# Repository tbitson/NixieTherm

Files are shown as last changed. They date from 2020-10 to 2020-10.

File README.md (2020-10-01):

# NixieTherm
 An analog nixie Tube Thermometer based on a IN-13 Nixie bar graph tube. Uses a Teensy 3.2 microcontroller to display temperature readings from a DS-18B20 1-wire temperature sensor.
 
 This is a n in-work project!
 
 Major hardware:
 IN-13 Nixie bar-graph tube (ebay.com)
 High voltage power supply module, such as a NCH8200HV 5V to 170V convertor (ebay.com)
 Teensy 3.2 microcontroller (PRJC.com)
 PC Board - eagle files included
 3D printed display mount and spacers - STL files included
 Laser cut acrylic display - laserdraw files included
 ULN2003 IC, RGB Leds, resistors, transistors...

 3D Printed objects available on TinkerCad.com
 https://www.tinkercad.com/things/9rIuJBIbugg-nixietherm/edit

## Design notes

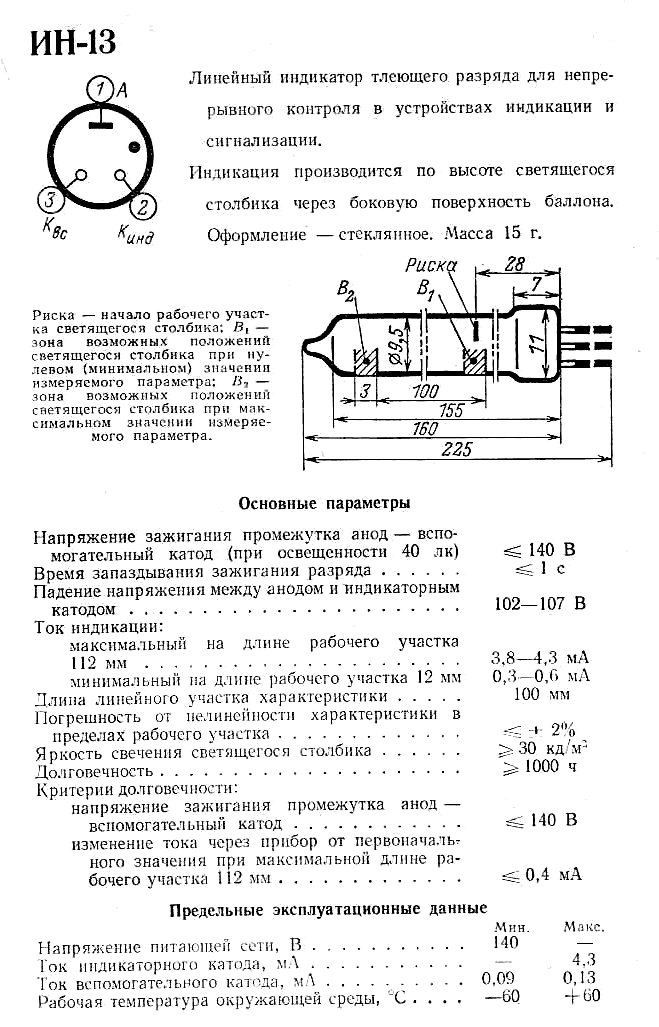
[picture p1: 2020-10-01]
Hardware/in-13-datasheet.gif

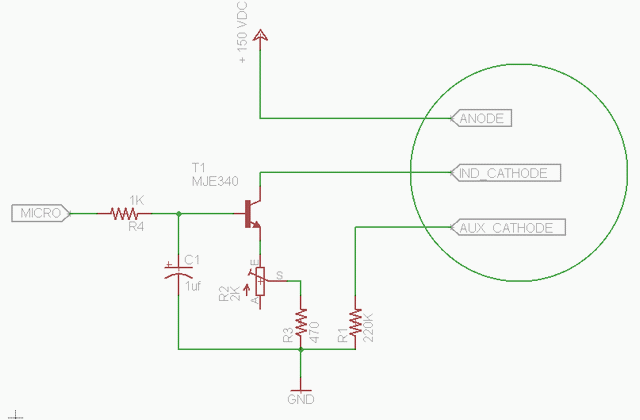
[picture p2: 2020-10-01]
Hardware/in13 schematic.gif

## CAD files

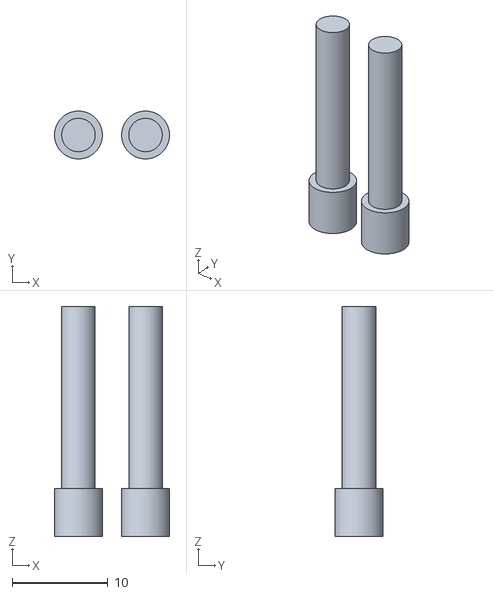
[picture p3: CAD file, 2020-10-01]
Hardware/3D Print Objects/NixieTherm Button Extenders.stl
12.0 x 5.00 x 24.0

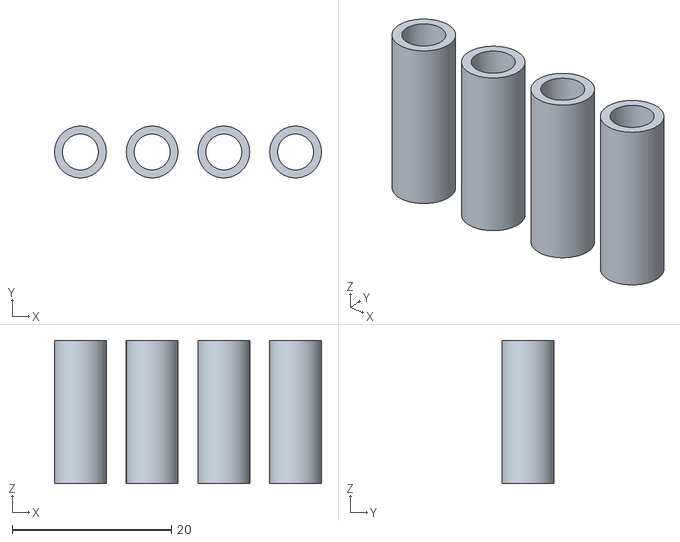
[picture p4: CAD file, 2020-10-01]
Hardware/3D Print Objects/NixieTherm Spacers.stl
33.5 x 6.50 x 18.0

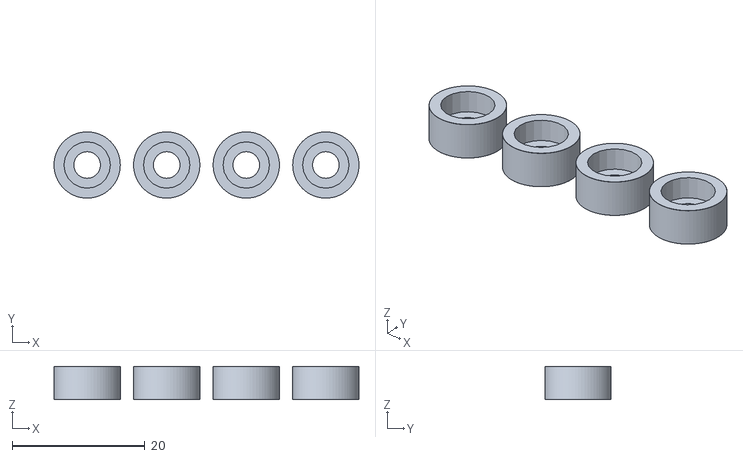
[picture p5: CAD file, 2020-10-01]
Hardware/3D Print Objects/NixieTherm Feet.stl
46.0 x 10.0 x 5.00

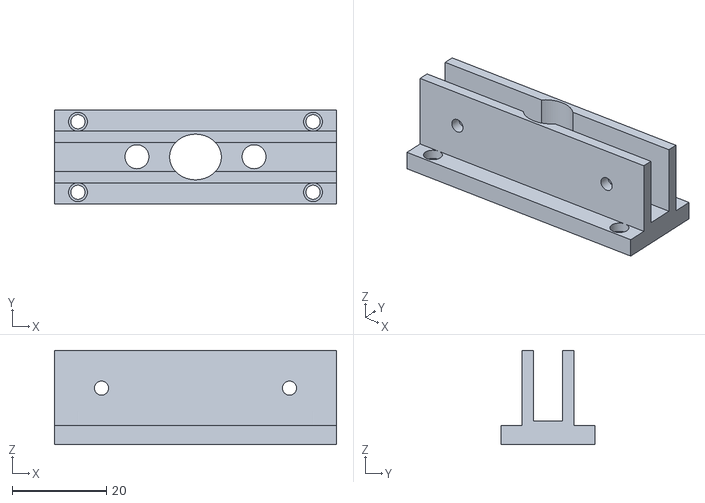
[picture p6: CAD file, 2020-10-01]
Hardware/3D Print Objects/NixieTherm Mount.stl
60.0 x 20.0 x 20.0

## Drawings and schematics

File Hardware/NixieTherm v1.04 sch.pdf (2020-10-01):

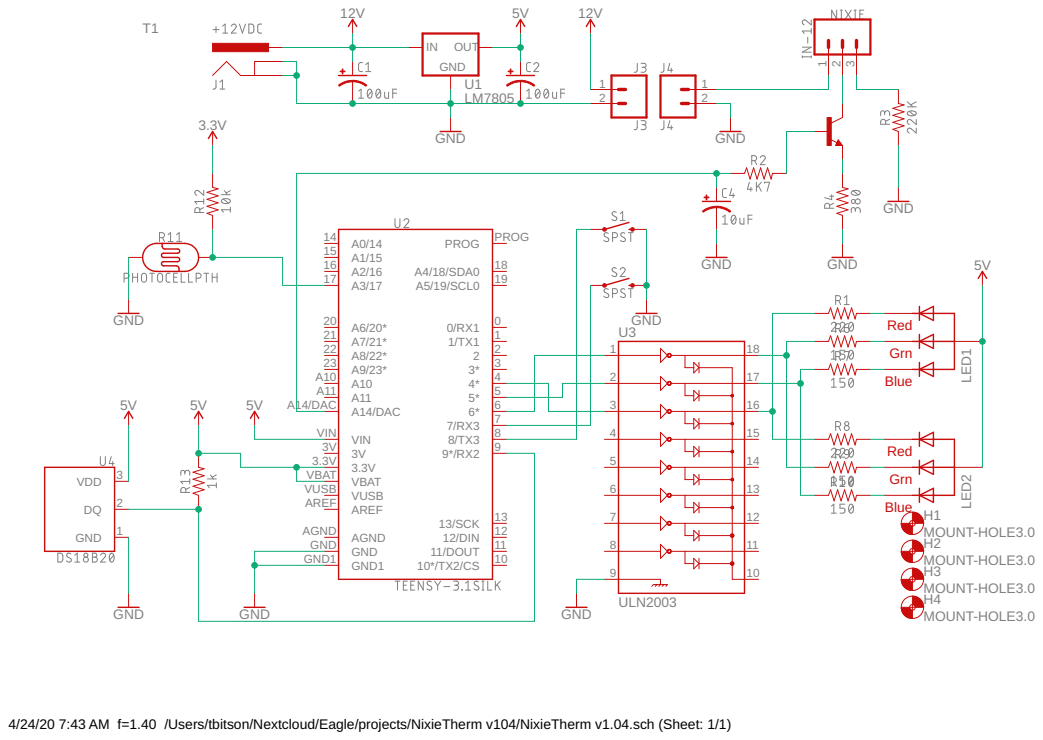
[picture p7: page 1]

4/24/20 7:43 AM f=1.40 /Users/tbitson/Nextcloud/Eagle/projects/NixieTherm v104/NixieTherm v1.04.sch (Sheet: 1/1)

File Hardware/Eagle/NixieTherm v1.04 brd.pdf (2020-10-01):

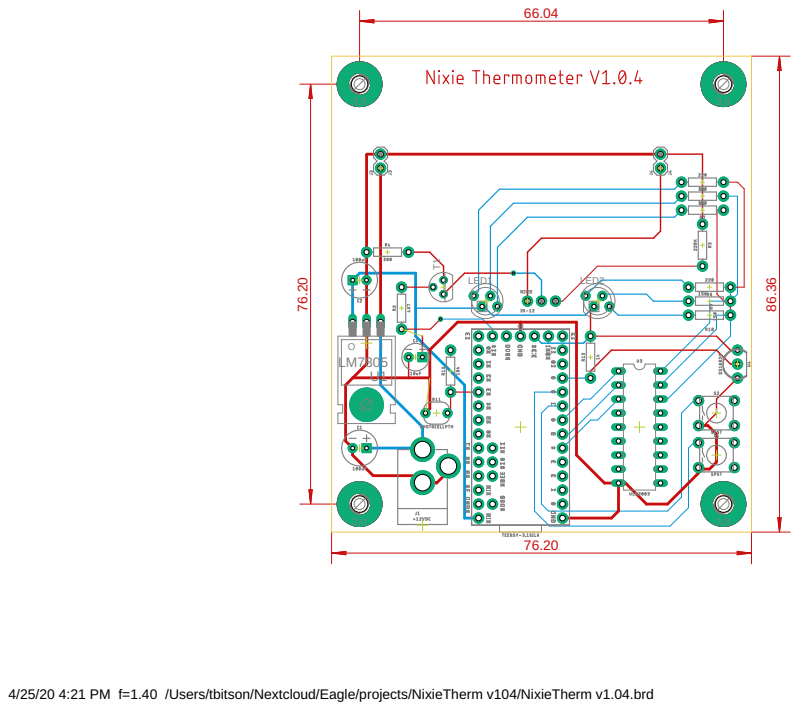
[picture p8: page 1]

4/25/20 4:21 PM f=1.40 /Users/tbitson/Nextcloud/Eagle/projects/NixieTherm v104/NixieTherm v1.04.brd

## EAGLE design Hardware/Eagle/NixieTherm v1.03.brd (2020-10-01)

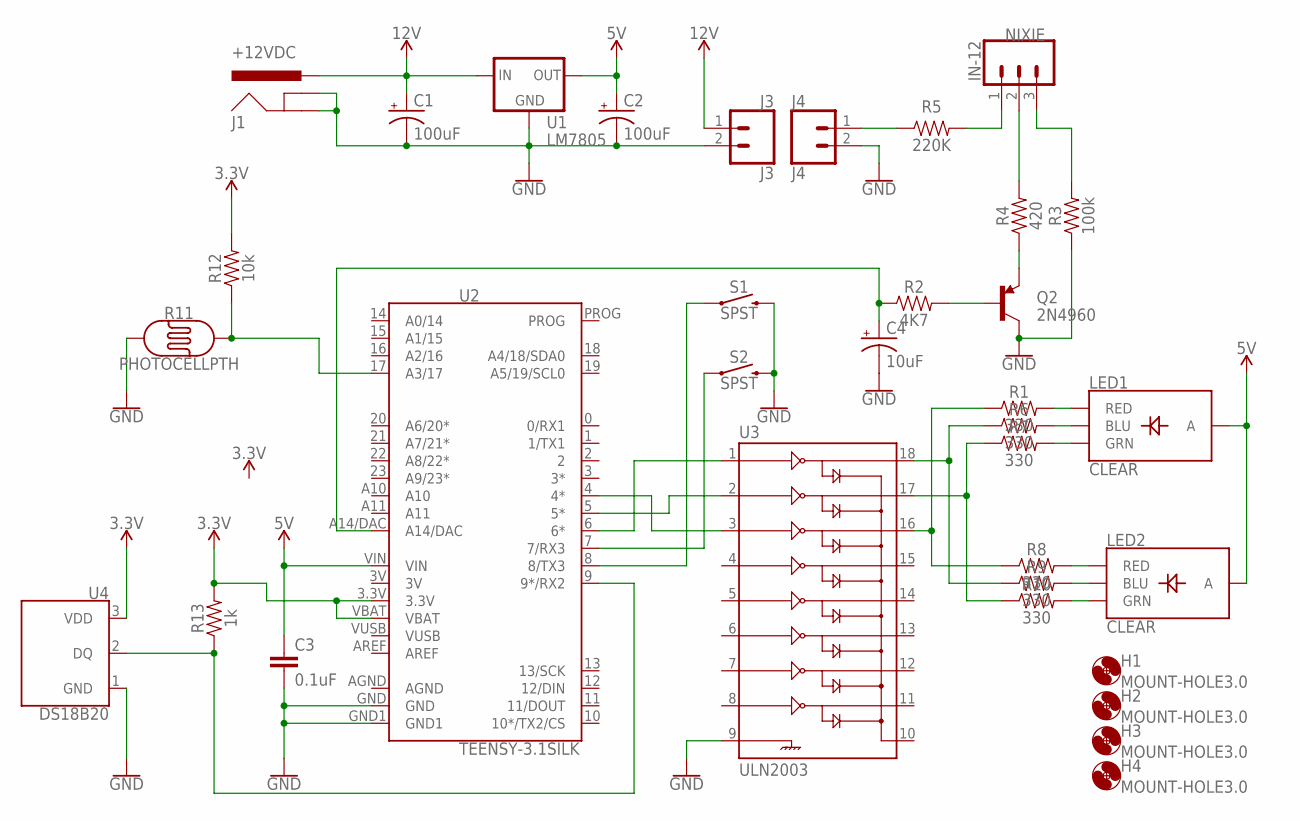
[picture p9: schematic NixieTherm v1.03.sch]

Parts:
C1, C2: 100uF; CPOL-RADIAL-2.5MM-6.5MM
C3: 0.1uF; CAP-PTH-SMALL-KIT
C4: 10uF; CPOL-RADIAL-2.5MM-5MM
H1, H2, H3, H4: MOUNT-HOLE3.0; 3,0
J1: +12VDC; POWER_JACK_PTH
J3: J3; 1X02
J4: J4; 1X02
LED1, LED2: CLEAR; LED-RGB-THRU
NIXIE: IN-12; 1X03_NO_SILK
Q2: 2N4960; TO-92
R1, R6, R7, R8, R9, R10: 330; AXIAL-0.3
R2: 4K7; AXIAL-0.3
R3: 100k; AXIAL-0.3
R4: 420; AXIAL-0.3
R5: 220K; AXIAL-0.3
R11: PHOTOCELLPTH; PHOTOCELL
R12: 10k; AXIAL-0.3
R13: 1k; AXIAL-0.3
S1, S2: SPST; TACTILE_SWITCH_PTH_6.0MM
U1: LM7805; TO-220-ALT
U2: TEENSY-3.1SILK; TEENSY-3.1
U3: ULN2003; DIL18
U4: DS18B20; TO-92-AMMO

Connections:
3.3V: R12.P$2 (2), R13.P$2 (2), U2.3.3V, U2.VBAT, U4.3 (VDD)
3V: U2.3V
5V: C2.1 (+), C3.1, LED1.2 (A), LED2.2 (A), U1.OUT, U2.VIN
12V: C1.1 (+), J1.PWR, J3.1, U1.IN
AGND: U2.AGND
GND: C1.2 (-), C2.2 (-), C3.2, C4.2 (-), J1.GND, J1.GNDBREAK, J3.2, J4.2, Q2.3 (C), R3.P$1 (1), R11.1, S1.3 (2), S2.3 (2), U1.GND, U2.GND, U2.GND1, U3.9, U4.1 (GND)
unnamed: R6.P$1 (1), R9.P$1 (1), U3.18
unnamed: R1.P$1 (1), R8.P$1 (1), U3.16
unnamed: R7.P$1 (1), R10.P$1 (1), U3.17
unnamed: NIXIE.1, R5.P$2 (2)
unnamed: NIXIE.3, R3.P$2 (2)
unnamed: NIXIE.2, R4.P$2 (2)
unnamed: Q2.2 (B), R2.P$2 (2)
unnamed: Q2.1 (E), R4.P$1 (1)
unnamed: C4.1 (+), R2.P$1 (1), U2.A14/DAC
unnamed: U2.4 (4*), U3.3
unnamed: U2.5 (5*), U3.2
unnamed: U2.6 (6*), U3.1
unnamed: S2.1, U2.7 (7/RX3)
unnamed: LED1.1 (RED), R1.P$2 (2)
unnamed: S1.1, U2.8 (8/TX3)
unnamed: LED1.4 (BLU), R6.P$2 (2)
unnamed: LED1.3 (GRN), R7.P$2 (2)
unnamed: LED2.1 (RED), R8.P$2 (2)
unnamed: LED2.4 (BLU), R9.P$2 (2)
unnamed: LED2.3 (GRN), R10.P$2 (2)
unnamed: J4.1, R5.P$1 (1)
unnamed: R11.2, R12.P$1 (1), U2.17 (A3/17)
unnamed: R13.P$1 (1), U2.9 (9*/RX2), U4.2 (DQ)
VUSB: U2.VUSB

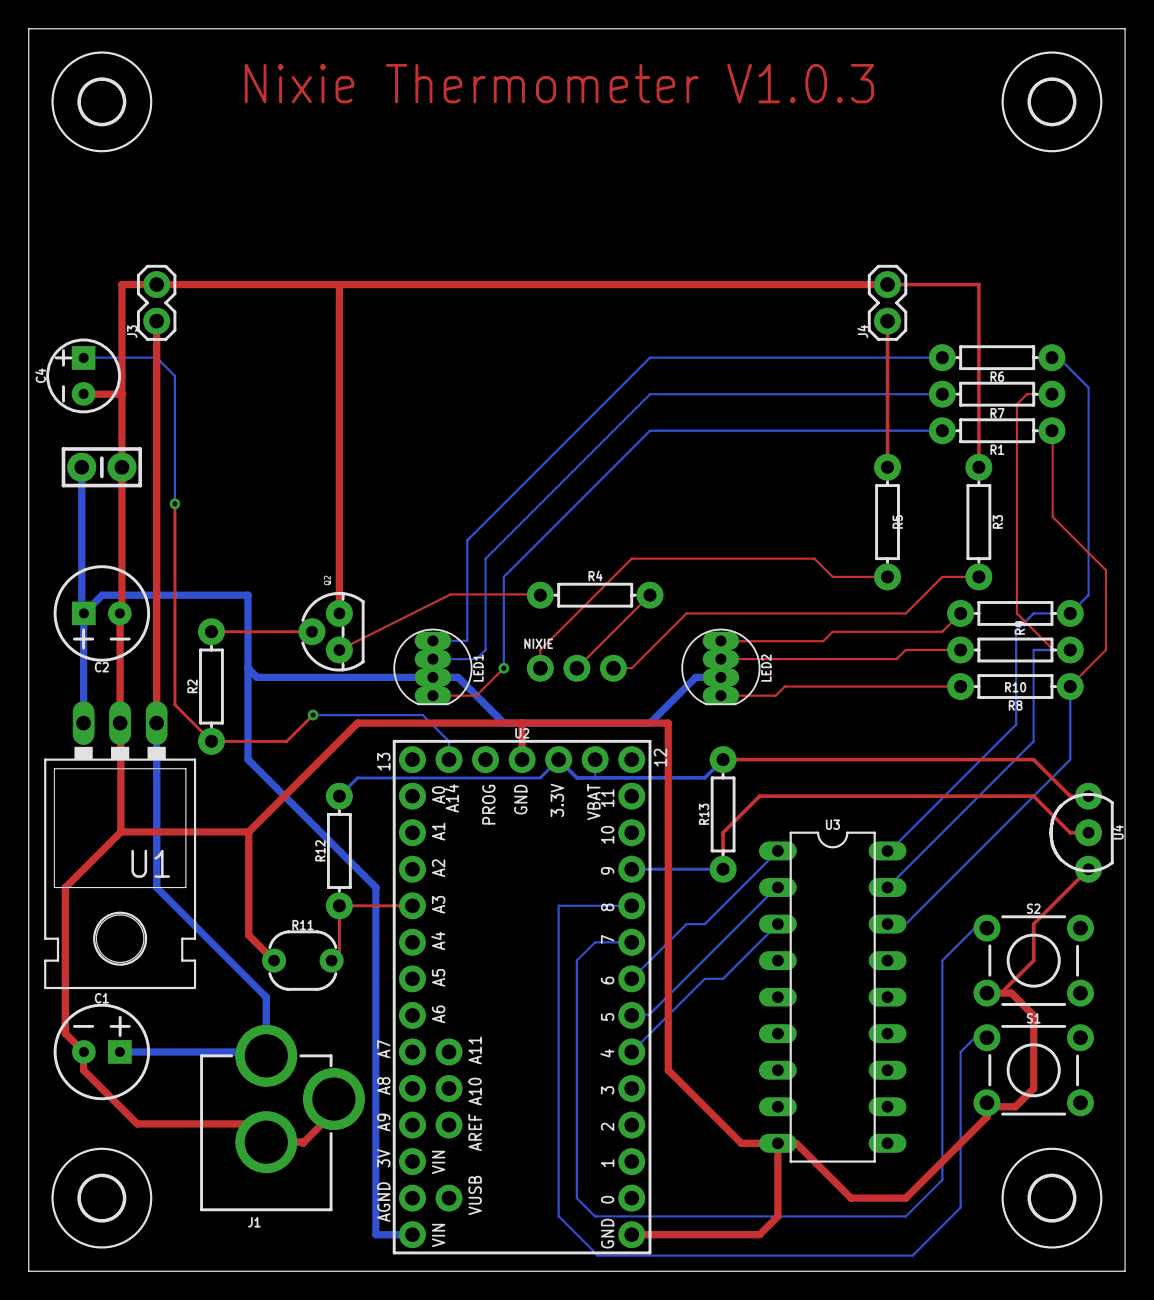
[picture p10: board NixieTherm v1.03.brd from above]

Board: 2 copper layers, 76.2 x 86.4 mm, 34 parts (0 on the bottom side), 27 nets.

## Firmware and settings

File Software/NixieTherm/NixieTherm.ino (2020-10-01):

/*************************************
    NixieTherm - Nixie IN-12 Thermometer
    Version 1.0.8  10Mayil2020  t.bitson

    Reads a DS18B20 1-wire temp sensor and
    displays results on a vintage Nixie IN-12
    bar-graph tube. Uses a Teensy 3.2 DAC ouput
    to drive the active cathode.

   Notes:
   12 bits = 4096 counts
   analogWriteResolution is set for 12 bit to accomodate
   Teensy's built-in DAC. This affects all analogWrite()
   functions, so the PWM for adjusting the LED brightness
   uses 12 bits.
   Use setLEDColor() for 1 of 6 basic colors or
   colorWheel12() for any of the 4096 colors


*****************************************************/

#define VERSION "NixieTherm Vers. 1.0.9  18Jun2020"



// uncomment to enable additional prints
//#define DEBUG

// select serial number for initial cal values
#define SN1
//#define SN2
//#define SN3


// hardware connections
// SN3 has unique wiring
#ifdef SN3
#define RED_LED      4
#define GRN_LED      3
#define BLU_LED      6
#else
#define RED_LED      4
#define GRN_LED      5
#define BLU_LED      6
#endif

#define PHOTO_CELL   A3
#define DAC_PIN      A14

#define SWITCH_1     7
#define SWITCH_2     8

#define ONE_WIRE_PIN 9
#define BUILTIN_LED  13

// states
#define ON      1
#define OFF     0


// global for interrupts
volatile uint16_t currentColor;   // current color


// program includes
#include <OneWire.h>
#include <Strings.h>
#include <EEPROM.h>

#include "leds.h"
#include "config.h"
#include "calibrate.h"
#include "interrupts.h"



// create instance of 1-wire temp sensor
OneWire ds(ONE_WIRE_PIN);

// global vars
bool calMode = false;     // flag to enter cal mode
uint32_t count = 0;       // loop counter
byte addr[8];             // 1-wire device address
int lastCounts = 0;        // last DAC setting in counts




//---------------------------------------------------------


void setup()
{
  // wait for things to settle
  delay(2000);

  // load config from nonvolatile memory
  loadConfig();


  Serial.println();
  Serial.println(VERSION);
  Serial.println(cfg.serialNum);
  Serial.println();

  // #ifdef DEBUG
  printConfig();
  // #endif

  // set up teensy DAC, drives nixie cathode
  analogWriteResolution(12);
  analogWrite(DAC_PIN, 0);

  // init hardware pins
  pinMode(RED_LED, OUTPUT);
  pinMode(GRN_LED, OUTPUT);
  pinMode(BLU_LED, OUTPUT);

  pinMode(BUILTIN_LED, OUTPUT);

  pinMode(SWITCH_1, INPUT_PULLUP);
  pinMode(SWITCH_2, INPUT_PULLUP);

  delay(500);

  // check for switch down at power up
  if (digitalRead(SWITCH_1) == 0)
    calMode = true;

  // check for switch down at power up
  if (digitalRead(SWITCH_2) == 0)
    testMode();

  // init DAC
  setDAC(60);

  // get temp sensor address
  getSensorAddress();

  // if first power up or cal mode selected
  if (calMode)
  {
    colorPicker(BLU);
    calibrate();
  }
  else
  {
    // cycle through all colors
    for (uint16_t i = 0; i < 4096; i++)
    {
      colorPicker(i);
      //delay(2);
    }
  }

  // cycle to selected color
  currentColor = cfg.displayColor;
  for (uint16_t i = 0; i < currentColor; i++)
  {
    colorPicker(i);
    delay(2);
  }

  // run through range
  exerciseNixie();

  // set up switch interrupts
  attachInterrupt(SWITCH_1, SW1_InterruptHandler, LOW);
  attachInterrupt(SWITCH_2, SW2_InterruptHandler, LOW);

  Serial.println("setup complete");
}




void loop()
{
  byte present = 0;
  byte data[12];
  float degsC, degsF;


  // exercise nixie approx once an hour
  if (count > 3600)
  {
    exerciseNixie();
    count = 0;
  }

  // led indicates we're getting the temperature
  digitalWrite(BUILTIN_LED, ON);

  ds.reset();           // reset 1-wire bus
  ds.select(addr);      // address device
  ds.write(0x44, 1);    // start conversion
  delay(1000);          // wait for temp conversion
  digitalWrite(BUILTIN_LED, OFF);

  present = ds.reset(); // reset bus & check if device is still present
  ds.select(addr);      // select device
  ds.write(0xBE);       // read temp data

  delay(100);

  if (present)
  {
    for (byte i = 0; i < 9; i++)
    {
      // we need 9 bytes
      data[i] = ds.read();
      //Serial.print(data[i], HEX);
      //Serial.print(" ");
    }

    uint8_t crc = OneWire::crc8(data, 8);
    //Serial.print(" calc CRC: ");
    //Serial.print(crc, HEX);
    //Serial.print(" should be: ");
    //Serial.println(data[8], HEX);

    if (data[8] != crc)
    {
      Serial.println("CRC Invalid");
      return;
    }

    int16_t raw = (data[1] << 8) | data[0];
    degsC = (float)raw / 16.0;
    degsF = degsC * 1.8 + 32.0;
    Serial.print("Temp = "); Serial.print(degsF, 1); Serial.println(" Degs F");
    setDAC(degsF);
    delay(5000);
  }
  else
  {
    Serial.println("Device not detected");
    delay(1000);
  }

  // increment loop counter
  count++;
}





void setDAC(float degs)
{
  int counts = 0;
  
  // full range is ~60 to ~90 degs, but calibrated at 65 and 85
  // calc 12-bit DAC value from temp

    float val = (degs - minTemp) * ((cfg.calValHigh - cfg.calValLow) / (maxTemp - minTemp)) + cfg.calValLow;
    counts = (int)val;
    Serial.print("counts = "); Serial.println(counts);

  // adjust nixie level incrementally, just for looks
  if (counts > lastCounts)
    for (int i = lastCounts; i < counts; i++)
    {
      analogWrite(DAC_PIN, i);
      delay(2);
    }

  if (counts < lastCounts)
    for (int i = lastCounts; i > counts; i--)
    {
      analogWrite(DAC_PIN, i);
      delay(2);
    }

  analogWrite(DAC_PIN, (int)counts);
  lastCounts = counts;
}




void getSensorAddress()
{
  // get the 1-wire temp sensor address
  // todo: store it in NV RAM
  //
  if (!ds.search(addr))
  {
    ds.reset_search();
    delay(250);
  }

  Serial.print("Temp Sensor Addr = {");
  for ( uint8_t i = 0; i < 8; i++)
  {
    Serial.print("0x");
    Serial.print(addr[i], HEX);
    Serial.print(", ");
  }
  Serial.println("}");

  if (OneWire::crc8(addr, 7) != addr[7])
    Serial.println("Warning: Invalid CRC");

  Serial.println();
  return;
}



void exerciseNixie()
{
  for (uint16_t i = fullOff; i < fullOn; i++)
  {
    analogWrite(DAC_PIN, i);
    delay(2);
  }

  for (uint16_t i = fullOn; i > fullOff; i--)
  {
    analogWrite(DAC_PIN, i);
    delay(2);
  }

  lastCounts = fullOff;
}




void testMode()
{
  Serial.println("test mode");
  
  while (true)
  {
    analogWrite(DAC_PIN, 700);
    delay(2000);
    analogWrite(DAC_PIN, 2900);
    delay(2000);

    if (digitalRead(SWITCH_1) == 0)
      return;
  }
}

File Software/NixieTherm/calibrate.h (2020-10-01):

/************************************************
   calibrate .h

   sets up DAC value for the nixie tube driver.


   Transistor for driving the dynamic cathode starts
   conduction at 0.7v. 0.7v =~ 869 counts on DAC, therefore:
   4096 - 869 = 3227 is usable calculated range of DAC.
   Testing shows that ~2400 counts is full scale with transistor
   gain. May opt to change cathode resistor
   compenstate for 0.7V drop in transistor
   full off = 4096 * (0.7 / 3.3) = 869
   full on = 4096, actually ends up 3269 based on
   transistor gain
   range ~= 3269 - 869 = 2400


 **********************************************/



#ifndef CALIBRATE_H
#define CALIBRATE_H





// calibration constants
const float fullOn    = 2900.0;
const float fullOff   = 700.0;
const float minTemp   = 60.0;
const float maxTemp   = 90.0;
const float calTempLo = 65.0;
const float calTempHi = 85.0;


extern void setDAC(float degs);


void calibrate()
{
  bool loop = true;

  Serial.println("Cal mode");
  Serial.println("Press switch 1 to decrease");
  Serial.println("Press switch 2 to increase");
  Serial.println("Press both to exit");

  while (loop)
  {
    while (digitalRead(SWITCH_2) || digitalRead(SWITCH_1))
    {
      // set dac for 65 degs
      setDAC(65);
      Serial.print("adjust for 65 Degs: ");

      if (digitalRead(SWITCH_1) == 0)
        cfg.calValLow -= 2;
      if (digitalRead(SWITCH_2) == 0)
        cfg.calValLow += 2;

      Serial.println(cfg.calValLow);
      delay(200);
    }

    delay(1000);

    while (digitalRead(SWITCH_2) || digitalRead(SWITCH_1))
    {
      // set dac to 85 degs
      setDAC(85);
      Serial.print("adjust for 85 Degs: ");

      if (digitalRead(SWITCH_1) == 0)
        cfg.calValHigh -= 2;
      if (digitalRead(SWITCH_2) == 0)
        cfg.calValHigh += 2;

      Serial.println(cfg.calValHigh);
      delay(200);
    }

    delay(500);

    if (digitalRead(SWITCH_2) == 0 && digitalRead(SWITCH_1) == 0)
      loop = false;
  }

  cfg.calComplete = true;

  saveConfig();

  Serial.print("Final Cal Values:");
  Serial.print("  min: "); Serial.print(cfg.calValLow);
  Serial.print("  max: "); Serial.print(cfg.calValHigh);
  Serial.println();
}

#endif

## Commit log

2020-10-01 NixieTherm Initial Release
    An IN-13 Nixie analog bar-graph thermometer.
    [NixieTherm Button Extenders.stl, NixieTherm Feet.stl, NixieTherm Mount.stl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]
2020-10-01 Added schematic
    Added schematic and updated readme
    [NixieTherm v1.03.brd, NixieTherm v1.03.sch]

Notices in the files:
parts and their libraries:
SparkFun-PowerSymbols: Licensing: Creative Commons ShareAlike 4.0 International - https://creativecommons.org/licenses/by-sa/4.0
